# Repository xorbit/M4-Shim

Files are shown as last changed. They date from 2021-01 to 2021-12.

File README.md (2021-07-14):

# M4-Shim
ARM Cortex M4 shim for PoE-FeatherWing, functionally equivalent to Feather M4 Express

You can buy it now on [Tindie](https://www.tindie.com/products/silicognition/m4-shim/)
or on [Amazon](https://www.amazon.com/M4-Shim-Feather-PoE-FeatherWing-Ultra-Compact-Vertical/dp/B0971PKDV7/)!

### Description

This is an adaptation of the excellent
[Adafruit Feather M4 Express](https://github.com/adafruit/Adafruit-Feather-M4-Express-PCB),
redesigned specifically for use with the equally excellent
[PoE-FeatherWing](https://hackaday.io/project/168356-poe-featherwing).

The goal was to create a compact system with Power over Ethernet, Ethernet connectivity and
a powerful processor capable of supporting [CircuitPython](https://circuitpython.org/).
Because of the bulky RJ45 jack and flyback transformer on the PoE-FeatherWing, it was not
possible to mount a traditional Feather on top.  This redesign takes the relevant circuitry
of the Adafruit Feather M4 Express and shapes it so it fits in the gaps between the
tall components of the PoE-FeatherWing.  This way it can be mounted on top for an extremely
compact solution.

The only thing missing versus the Feather M4 Express is the battery support circuitry,
which did not seem necessary in a PoE design.

The hardware is sold with the [UF2 bootloader](https://github.com/adafruit/uf2-samdx1)
and [CircuitPython](https://github.com/adafruit/circuitpython) pre-installed.

### License

This redesign by Silicognition LLC is licensed as Creative Commons Attribution/Share-Alike,
just like the Adafruit Feather M4 Express it is based on.

Original Adafruit license statement:

Adafruit invests time and resources providing this open source design, please support Adafruit and open-source hardware by purchasing products from [Adafruit](https://www.adafruit.com)!

Designed by Limor Fried/Ladyada for Adafruit Industries.

Creative Commons Attribution/Share-Alike, all text above must be included in any redistribution. See LICENSE for additional details.

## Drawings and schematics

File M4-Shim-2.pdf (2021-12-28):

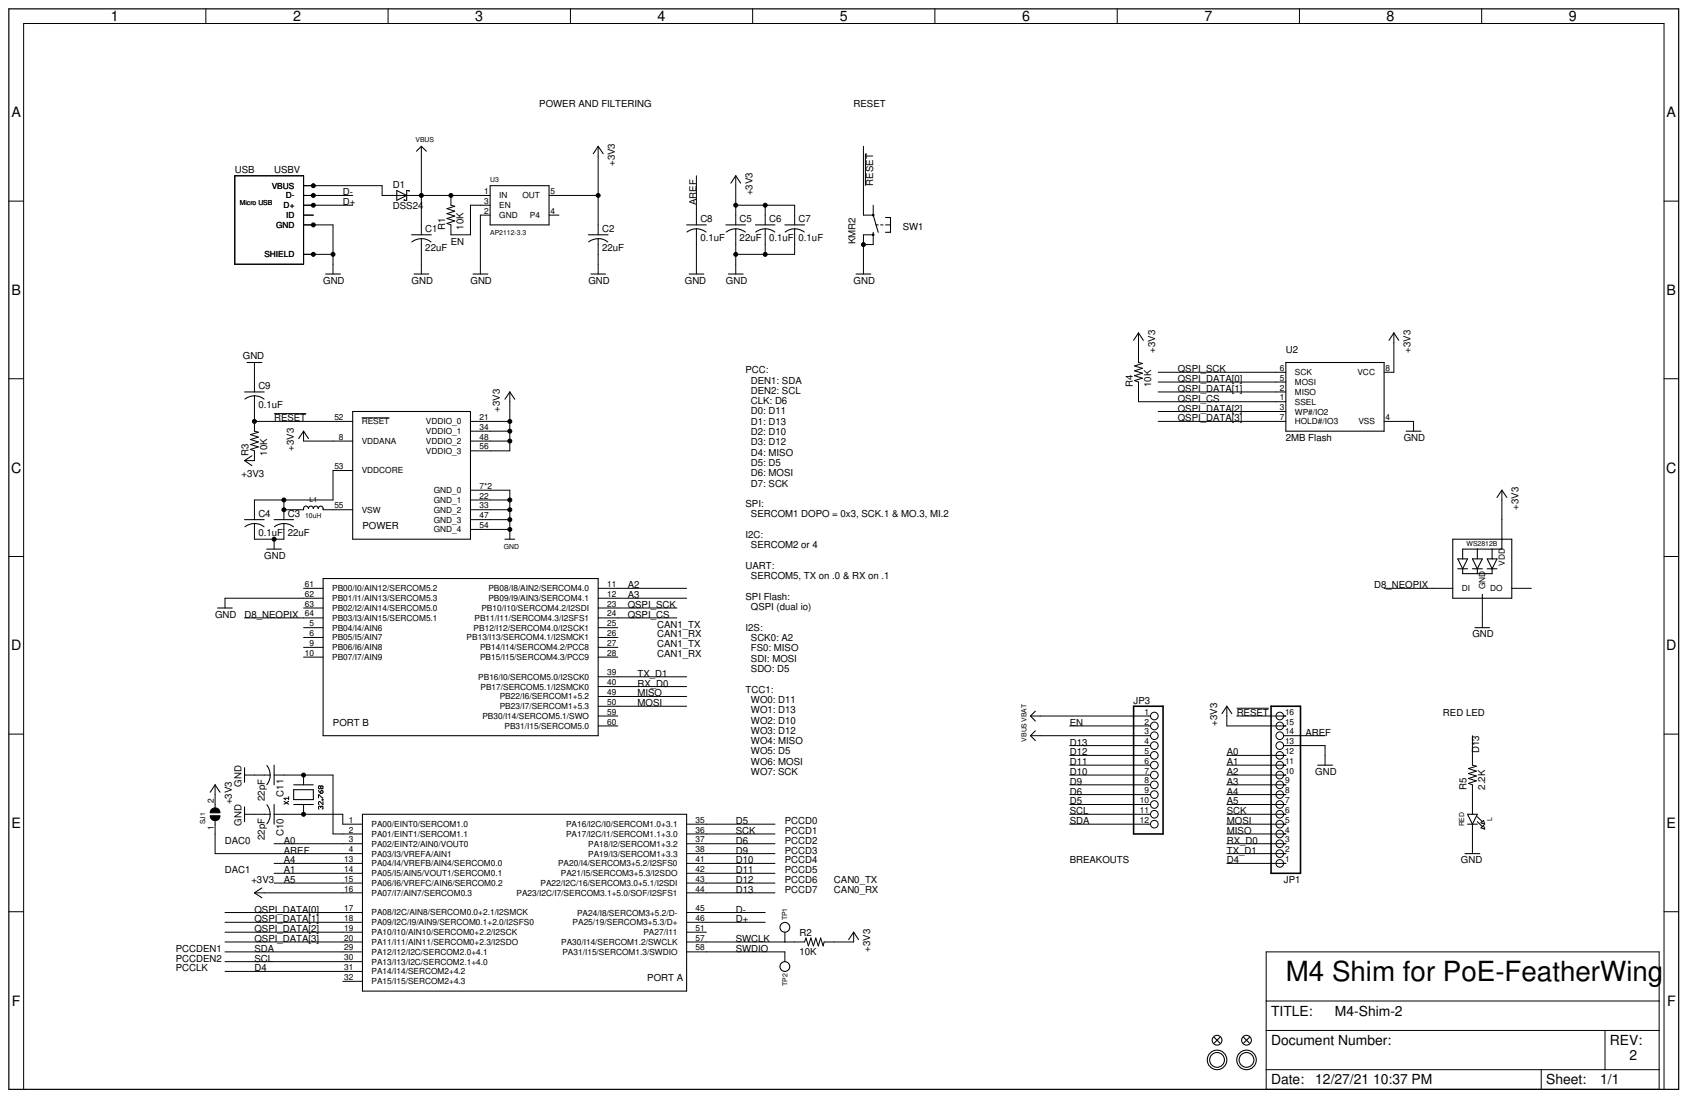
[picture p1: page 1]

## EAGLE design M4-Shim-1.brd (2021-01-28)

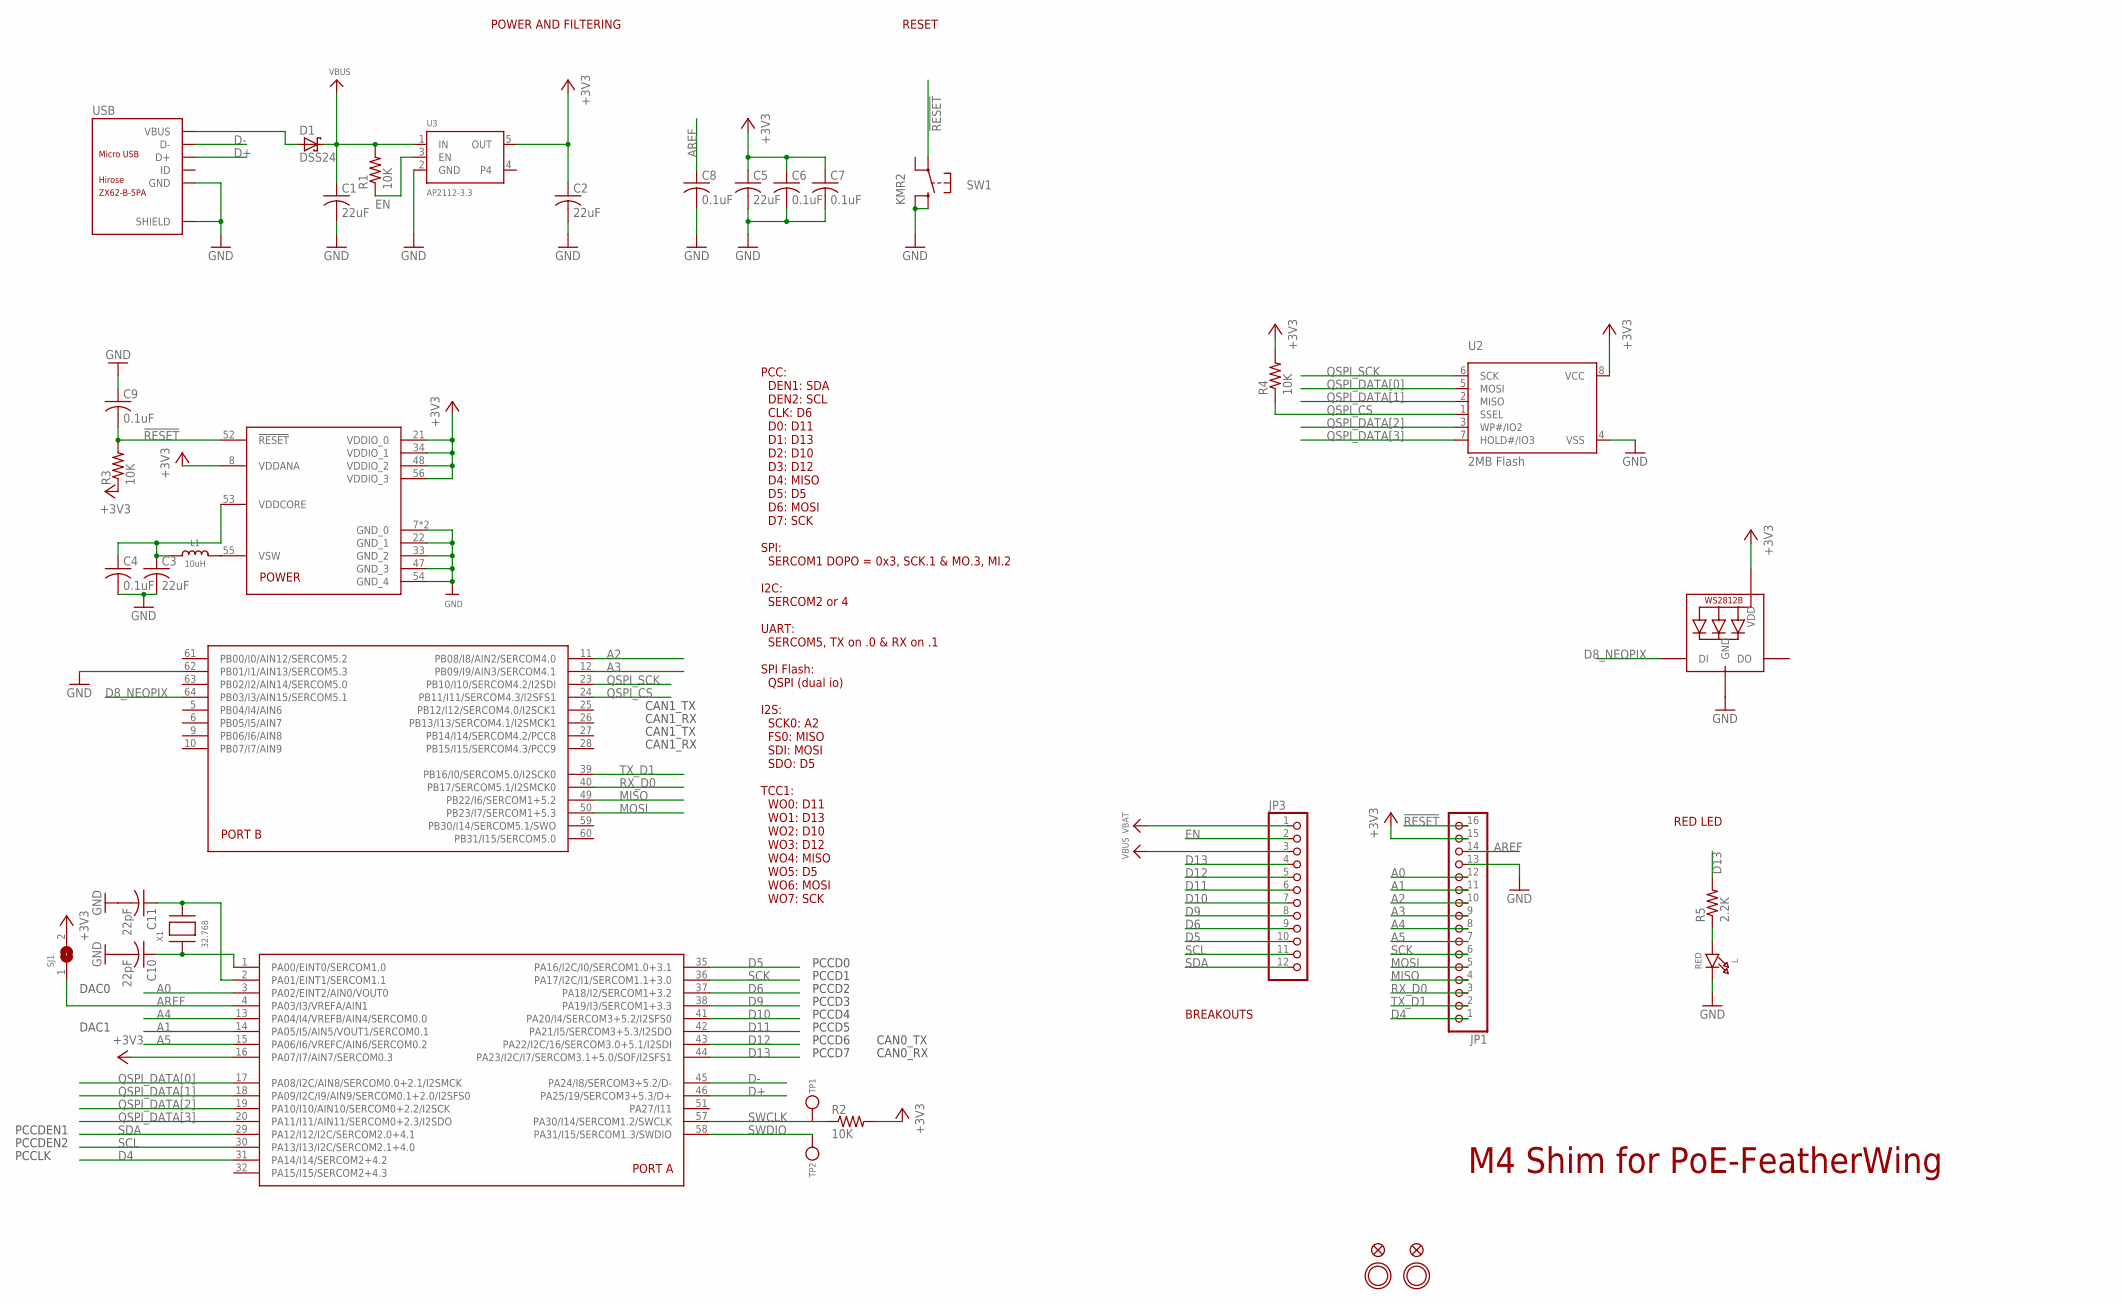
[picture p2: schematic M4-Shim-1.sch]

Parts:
C1, C2, C3, C5: 22uF; C0805K
C4, C6, C7, C8, C9: 0.1uF; C0402K
C10, C11: 22pF; C0402K
D1: DSS24; SOD123FL
JP1: HEADER-1X16ROUND; 1X16_ROUND
JP3: HEADER-1X12; 1X12_ROUND
L: RED; CHIPLED_0805_NOOUTLINE
L1: 10uH; INDUCTOR_1007
LED1: WS2812B3535; LED3535
R1, R2, R3, R4: 10K; R0402
R5: 2.2K; R0402
SJ1: SOLDERJUMPERCLOSED; SOLDERJUMPER_CLOSEDWIRE
SW1: KMR2; BTN_KMR2_4.6X2.8
TP1, TP2: TESTPOINTROUND1.5MM; TESTPOINT_ROUND_1.5MM
U1: ATSAMD51J; PQFN64-1
U2: 2MB Flash; USON8
U3: AP2112-3.3; SOT23-5
U$31, U$32: MOUNTINGHOLE2.5; MOUNTINGHOLE_2.5_PLATED
U$34, U$35: FIDUCIAL_1MM
USB: ZX62-B-5PA; MICRO-USB5+6P-SMD-0.65-AB
X1: 32.768; XTAL3215

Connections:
!RESET: C9.2, JP1.16, R3.2, SW1.A, U1.52 (!RESET)
+3V3: C2.1, C5.1, C6.1, C7.1, JP1.15, LED1.2 (VDD), R2.2, R3.1, R4.2, SJ1.2, U1.8 (VDDANA), U1.16 (PA07/I7/AIN7/SERCOM0.3), U1.21 (VDDIO_0), U1.34 (VDDIO_1), U1.48 (VDDIO_2), U1.56 (VDDIO_3), U2.8 (VCC), U3.5 (OUT)
A0: JP1.12, U1.3 (PA02/EINT2/AIN0/VOUT0)
A1: JP1.11, U1.14 (PA05/I5/AIN5/VOUT1/SERCOM0.1)
A2: JP1.10, U1.11 (PB08/I8/AIN2/SERCOM4.0)
A3: JP1.9, U1.12 (PB09/I9/AIN3/SERCOM4.1)
A4: JP1.8, U1.13 (PA04/I4/VREFB/AIN4/SERCOM0.0)
A5: JP1.7, U1.15 (PA06/I6/VREFC/AIN6/SERCOM0.2)
AREF: C8.1, JP1.14, SJ1.1, U1.4 (PA03/I3/VREFA/AIN1)
D4: JP1.1, U1.31 (PA14/I14/SERCOM2+4.2)
D5: JP3.10, U1.35 (PA16/I2C/I0/SERCOM1.0+3.1)
D6: JP3.9, U1.37 (PA18/I2/SERCOM1+3.2)
D8_NEOPIX: LED1.1 (DI), U1.64 (PB03/I3/AIN15/SERCOM5.1)
D9: JP3.8, U1.38 (PA19/I3/SERCOM1+3.3)
D10: JP3.7, U1.41 (PA20/I4/SERCOM3+5.2/I2SFS0)
D11: JP3.6, U1.42 (PA21/I5/SERCOM3+5.3/I2SDO)
D12: JP3.5, U1.43 (PA22/I2C/16/SERCOM3.0+5.1/I2SDI)
D13: JP3.4, R5.2, U1.44 (PA23/I2C/I7/SERCOM3.1+5.0/SOF/I2SFS1)
D+: U1.46 (PA25/19/SERCOM3+5.3/D+), USB.3 (D+)
D-: U1.45 (PA24/I8/SERCOM3+5.2/D-), USB.2 (D-)
EN: JP3.2, R1.1, U3.3 (EN)
GND: C1.2, C2.2, C3.2, C4.2, C5.2, C6.2, C7.2, C8.2, C9.1, C10.2, C11.2, JP1.13, L.C, LED1.4 (GND), SW1.B (S), SW1.B' (S1), U1.7 (GND_0), U1.22 (GND_1), U1.33 (GND_2), U1.47 (GND_3), U1.54 (GND_4), U1.62 (PB01/I1/AIN13/SERCOM5.3), U1.EXP (GND_0), U2.4 (VSS), U3.2 (GND), USB.5 (GND), USB.P1 (SHIELD), USB.P2 (SHIELD), USB.P3 (SHIELD), USB.P4 (SHIELD), USB.P5 (SHIELD), USB.P6 (SHIELD)
MISO: JP1.4, U1.49 (PB22/I6/SERCOM1+5.2)
MOSI: JP1.5, U1.50 (PB23/I7/SERCOM1+5.3)
unnamed: L.A, R5.1
unnamed: C10.1, U1.1 (PA00/EINT0/SERCOM1.0), X1.P$1
unnamed: C11.1, U1.2 (PA01/EINT1/SERCOM1.1), X1.P$2
unnamed: L1.P$2 (2), U1.55 (VSW)
QSPI_CS: R4.1, U1.24 (PB11/I11/SERCOM4.3/I2SFS1), U2.1 (SSEL)
QSPI_DATA[0]: U1.17 (PA08/I2C/AIN8/SERCOM0.0+2.1/I2SMCK), U2.5 (MOSI)
QSPI_DATA[1]: U1.18 (PA09/I2C/I9/AIN9/SERCOM0.1+2.0/I2SFS0), U2.2 (MISO)
QSPI_DATA[2]: U1.19 (PA10/I10/AIN10/SERCOM0+2.2/I2SCK), U2.3 (WP#/IO2)
QSPI_DATA[3]: U1.20 (PA11/I11/AIN11/SERCOM0+2.3/I2SDO), U2.7 (HOLD#/IO3)
QSPI_SCK: U1.23 (PB10/I10/SERCOM4.2/I2SDI), U2.6 (SCK)
RX_D0: JP1.3, U1.40 (PB17/SERCOM5.1/I2SMCK0)
SCK: JP1.6, U1.36 (PA17/I2C/I1/SERCOM1.1+3.0)
SCL: JP3.11, U1.30 (PA13/I13/I2C/SERCOM2.1+4.0)
SDA: JP3.12, U1.29 (PA12/I12/I2C/SERCOM2.0+4.1)
SWCLK: R2.1, TP1.P$1, U1.57 (PA30/I14/SERCOM1.2/SWCLK)
SWDIO: TP2.P$1, U1.58 (PA31/I15/SERCOM1.3/SWDIO)
TX_D1: JP1.2, U1.39 (PB16/I0/SERCOM5.0/I2SCK0)
VBAT: JP3.1
VBUS: C1.1, D1.C, JP3.3, R1.2, U3.1 (IN)
VBUSEXT: D1.A, USB.1 (VBUS)
VDDCORE1: C3.1, C4.1, L1.P$1 (1), U1.53 (VDDCORE)

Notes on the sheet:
POWER AND FILTERING
RESET
BREAKOUTS
RED LED
PCCDEN1
PCCDEN2
PCCD0
PCCD1
PCCD2
PCCD3
PCCD4
PCCD5
PCCD6
PCCD7
PCCLK
PCC: DEN1: SDA DEN2: SCL CLK: D6 D0: D11 D1: D13 D2: D10 D3: D12 D4: MISO D5: D5 D6: MOSI D7: SCK SPI: SERCOM1 DOPO = 0x3, SCK.1 & MO.3, MI.2 I2C: SERCOM2 or 4 UART: SERCOM5, TX on .0 & RX on .1 SPI Flash: QSPI (dual io) I2S: SCK0: A2 FS0: MISO SDI: MOSI SDO: D5 TCC1: WO0: D11 WO1: D13 WO2: D10 WO3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
CAN0_TX
CAN0_RX
DAC0
DAC1
CAN1_TX
CAN1_RX
M4 Shim for PoE-FeatherWing

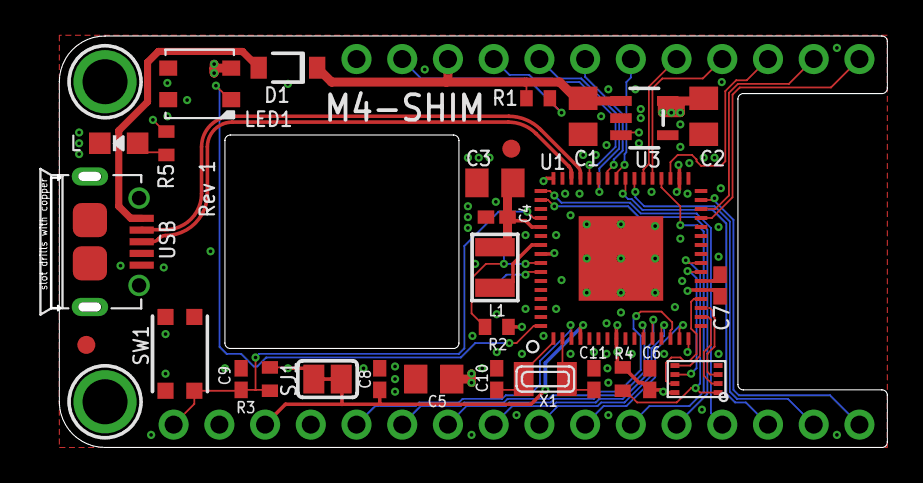
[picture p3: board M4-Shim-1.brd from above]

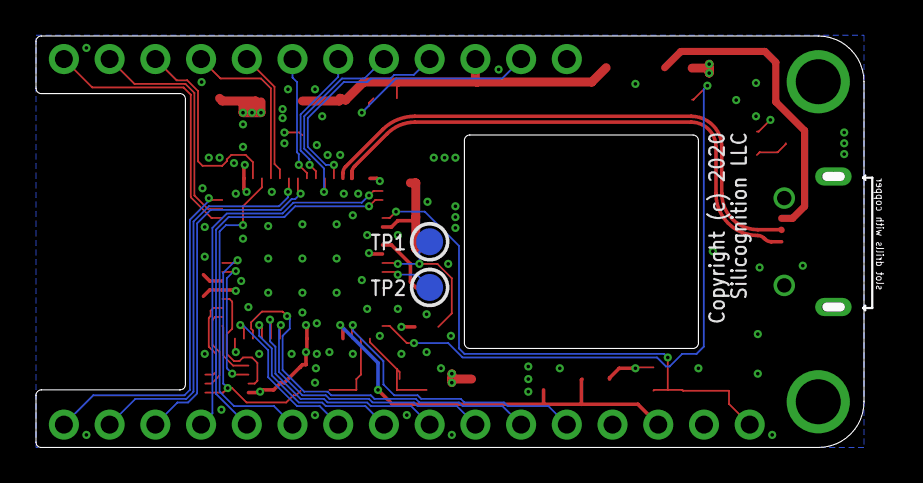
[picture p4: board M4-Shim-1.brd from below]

Board: 4 copper layers, 46.0 x 22.9 mm, 35 parts (2 on the bottom side), 44 nets.

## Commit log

2021-01-28 Initial commit of rev 1 and rev 2
    [M4-Shim-1.brd, M4-Shim-1.sch, M4-Shim-2.brd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]
2021-01-30 Add software links for UF2 bootloader and CircuitPython
2021-12-28 Add PDF of rev 2 schematic
    [M4-Shim-2.sch]

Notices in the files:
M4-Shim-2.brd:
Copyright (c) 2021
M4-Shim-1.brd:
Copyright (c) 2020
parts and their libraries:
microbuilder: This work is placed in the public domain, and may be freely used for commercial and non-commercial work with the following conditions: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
